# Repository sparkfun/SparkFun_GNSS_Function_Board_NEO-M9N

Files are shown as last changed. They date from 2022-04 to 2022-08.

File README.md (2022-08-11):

SparkFun MicroMod GNSS Function Board - NEO-M9N
========================================

SparkFun MicroMod GNSS Function Board - NEO-M9N (https://www.sparkfun.com/products/18378)

[*SparkFun MicroMod GNSS Function Board - NEO-M9N (GPS-18378)*](https://www.sparkfun.com/products/18378)

The SparkFun NEO-M9N GNSS Function Board is a high quality, geospatial board with equally impressive configuration options. The NEO-M9N module that is populated on this board is a 92-channel u-blox M9 engine GNSS receiver, meaning it can receive signals from the GPS, GLONASS, Galileo, and BeiDou constellations with ~1.5 meter accuracy. This Function Board supports concurrent reception of four GNSS. This maximizes position accuracy in challenging conditions, increasing precision and decreases lock time; and thanks to the on-board rechargeable battery, you'll have backup power enabling the GPS to get a hot lock within seconds!

Utilizing our handy M.2 MicroMod connector, no soldering is required to connect it to your system. Simply match up the key on your processor and function board's beveled edge connector to their respective key on the M.2 connector, then secure them to the Main Board with screws. Once connected, you'll have the option of choosing either the UART, SPI, or I<sup>2</sup>C (u-blox calls this Display Data Channel) port to communicate with the NEO-M9N.

The NEO-M9N module detects jamming and spoofing events and can reports them to the host, so that the system can react to such events. A SAW (Surface Acoustic Wave) filter combined with an LNA (Low Noise Amplifier) in the RF path is integrated into the NEO-M9N module which allows normal operation even under strong RF interferences.

U-blox based GPS products are configurable using the popular, but dense, Windows program called u-center. Plenty of different functions can be configured on the NEO-M9N: baud rates, update rates, geofencing, spoofing detection, external interrupts, SBAS/D-GPS, etc. All of this can be done within the [SparkFun Arduino Library](https://github.com/sparkfun/SparkFun_u-blox_GNSS_Arduino_Library) via the I<sup>2</sup>C bus!

The SparkFun GNSS Function Board - NEO-M9N includes a USB type C connector when configuring the module with u-center. Power is provided through the Function Board's edge pins and regulated down through the 3.3V voltage regulator. Two status LEDs are also included for 3V3 and PPS, which can be disabled by cutting the jumpers on the back of the board. A 1x3 header is populated on the board and includes a 2-pin selectable jumper when selecting the communication protocol between SPI or Serial/I<sup>2</sup>C. For advanced users, there are jumpers to disable the write protection for the EEPROM (WP), disconnecting the pull-up resistors (I2C), and placing the module in safe boot mode (SAFEBOOT). A U.FL connector is provided to connect a GNSS antenna of your choice to the module.  The board is equipped with an on-board rechargeable battery that provides power to the RTC on the NEO-M9N.  This reduces the time-to-first fix from a cold start (~24s) to a hot start (~2s). The battery will maintain RTC and GNSS orbit data without being connected to power for plenty of time. 

Repository Contents
-------------------

* **/Hardware** - Eagle design files (.brd, .sch)
* **/Production** - Production panel files (.brd)

Documentation
--------------

* **[Installing an Arduino Library Guide](https://learn.sparkfun.com/tutorials/installing-an-arduino-library/all)** - Basic information on how to install an Arduino library.
* **[Library](https://github.com/sparkfun/SparkFun_u-blox_GNSS_Arduino_Library)** - Arduino Library the SparkFun MicroMod GNSS Function Board - NEO-M9N.
* **[Hookup Guide](https://learn.sparkfun.com/tutorials/1999)** - Basic hookup guide for the SparkFun MicroMod GNSS Function Board - NEO-M9N.

Product Versions
----------------

* [GPS-18378](https://www.sparkfun.com/products/18378) - Initial release

Version History
---------------

* v1.2 - Initial Release

License Information
-------------------

This product is _**open source**_! 

Please review the LICENSE.md file for license information. 

If you have any questions or concerns on licensing, please contact technical support on our [SparkFun forums](https://forum.sparkfun.com/viewforum.php?f=152).

Distributed as-is; no warranty is given.

- Your friends at SparkFun.

_<COLLABORATION CREDIT>_

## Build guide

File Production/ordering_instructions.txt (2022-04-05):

panel size, 128x137mm
PCB thickness, 0.8mm
number of layers, 2
bevel, Gold Fingers + 45° Finger Chamfered
soldermask color, Red
silkscreen color, White
oz copper, 1oz
finish, ENIG
stencils, top
pcs per panel, 6
min trace width, 0.2032mm / 0.0080in
min drill size, 0.3048mm / 0.0120in

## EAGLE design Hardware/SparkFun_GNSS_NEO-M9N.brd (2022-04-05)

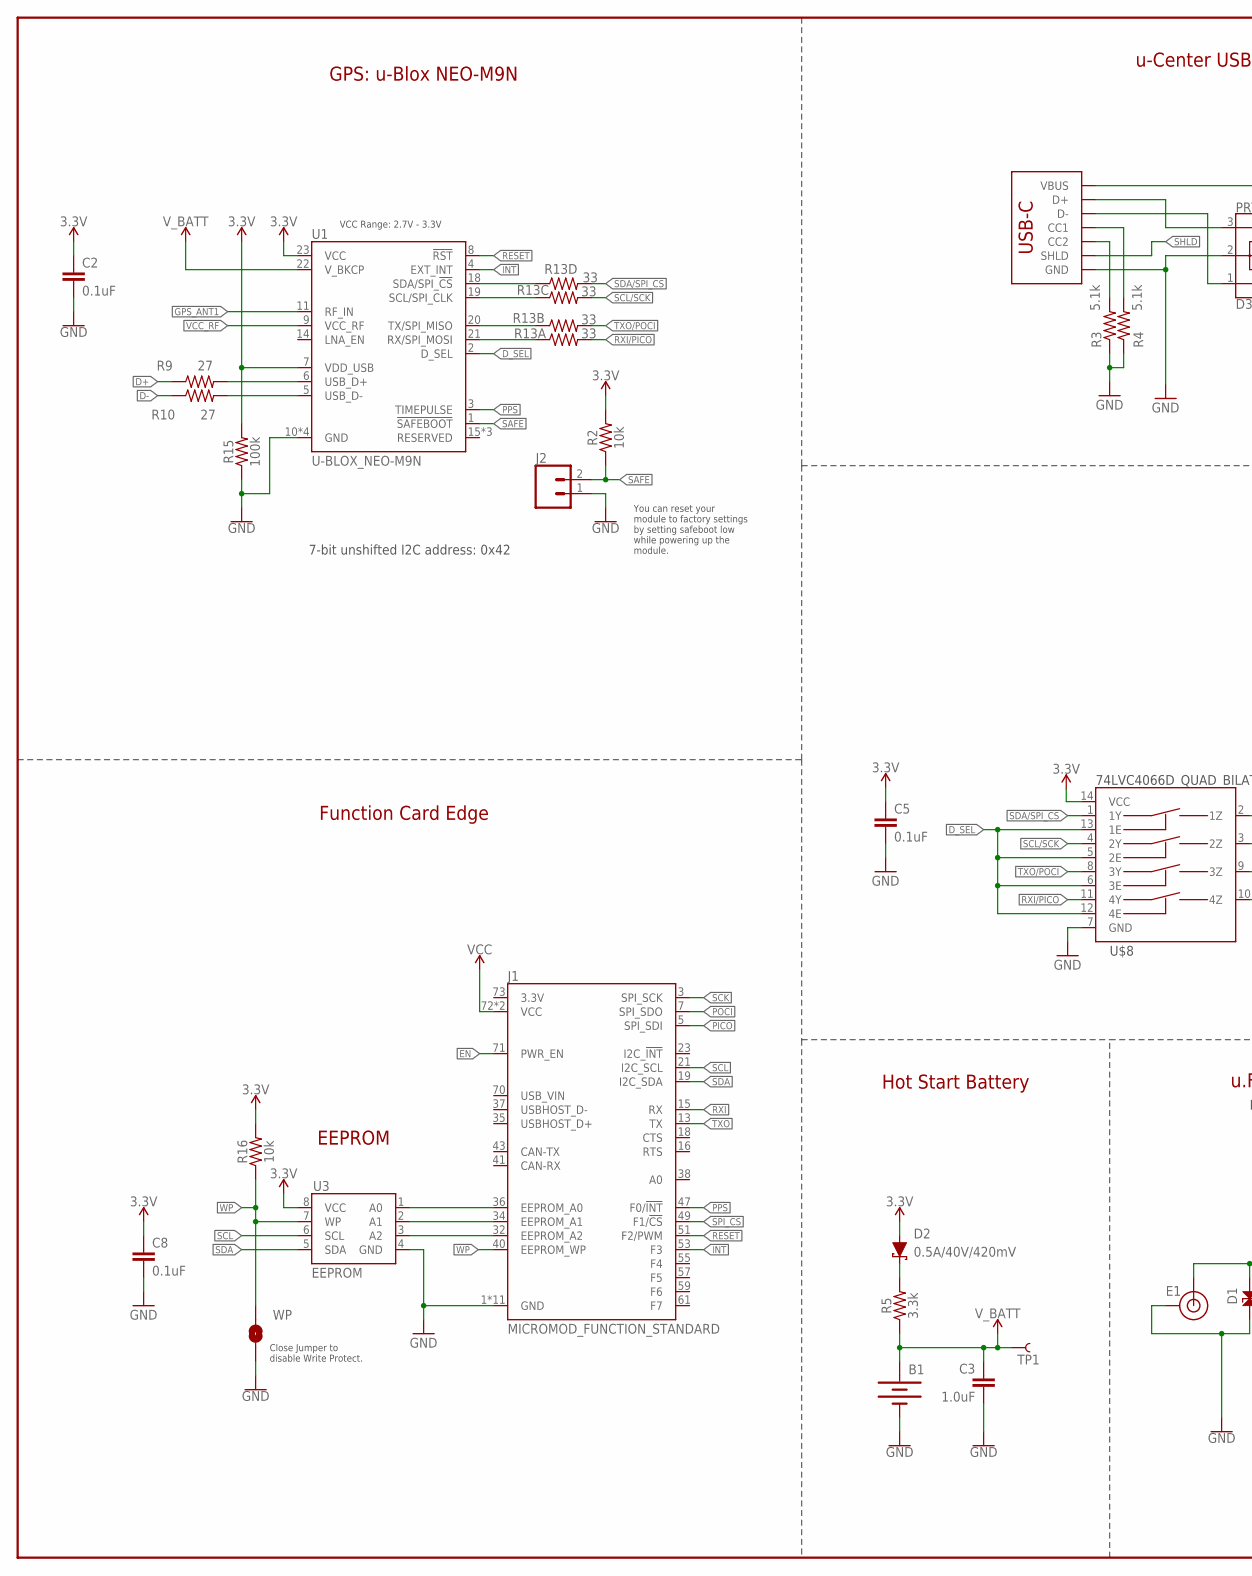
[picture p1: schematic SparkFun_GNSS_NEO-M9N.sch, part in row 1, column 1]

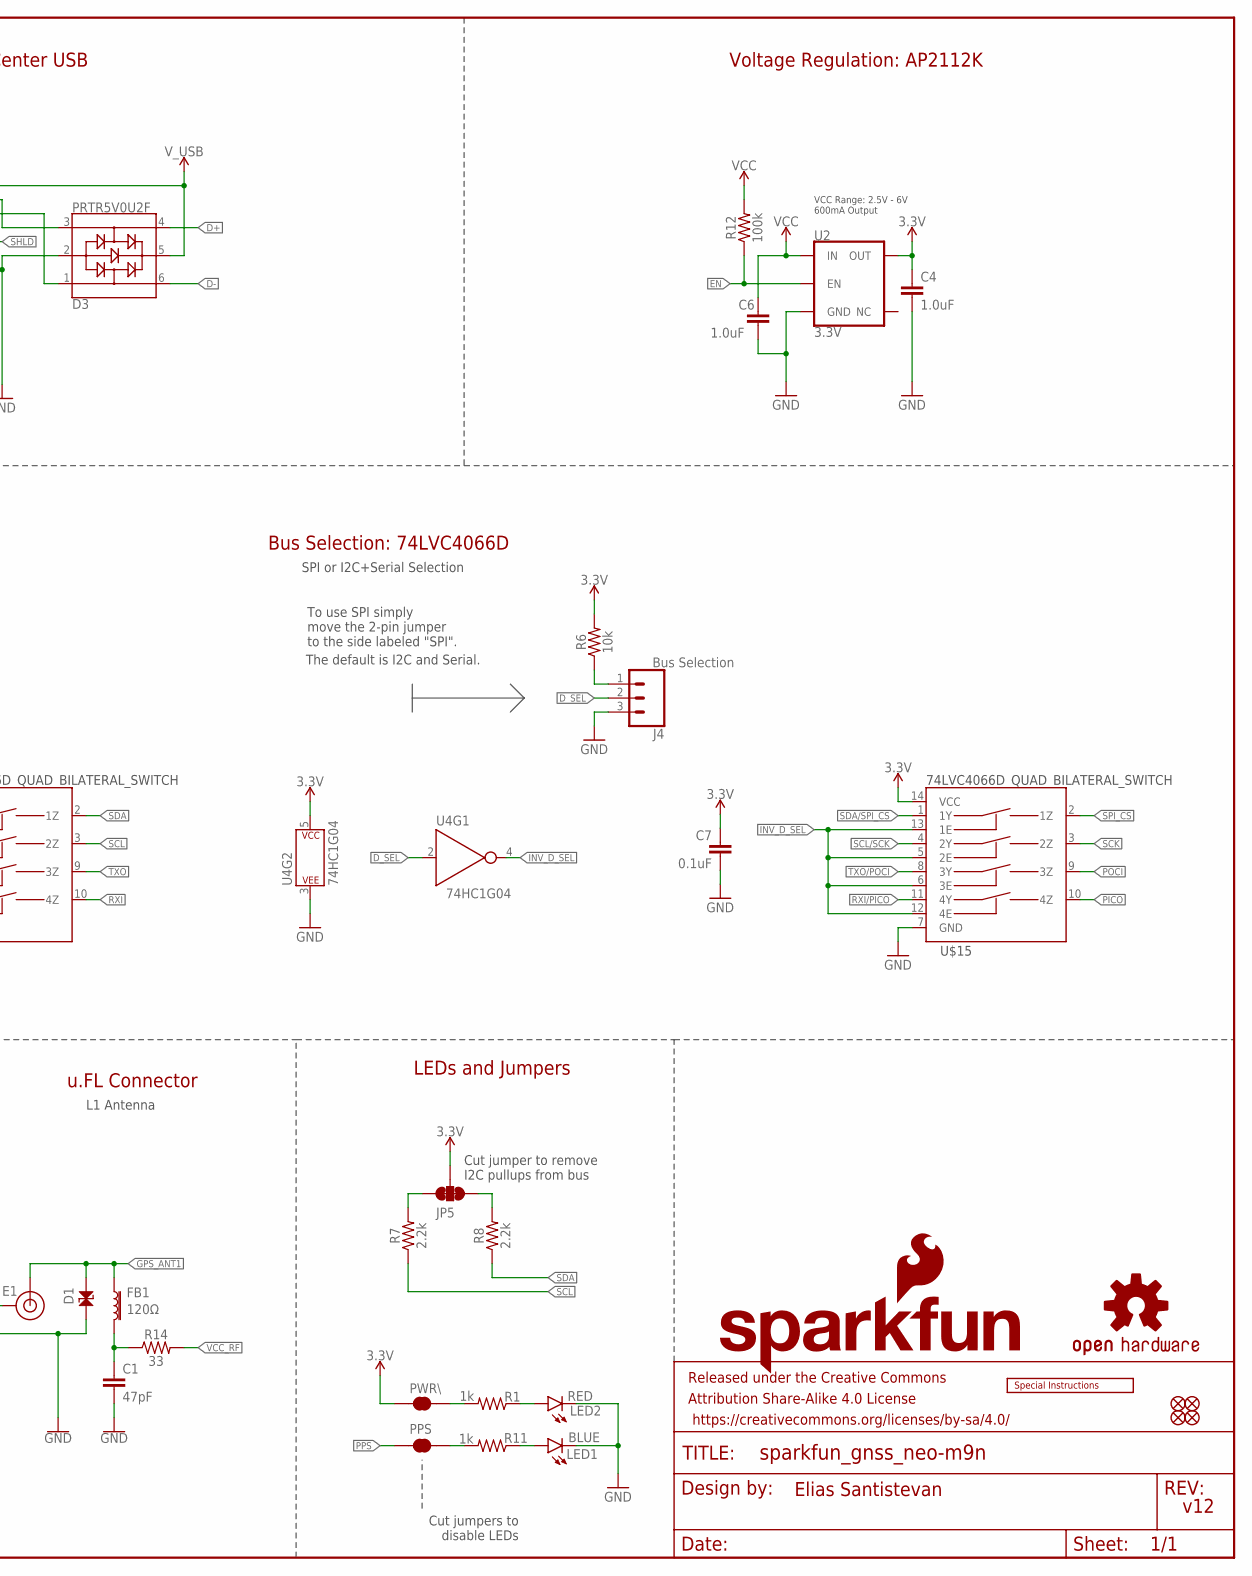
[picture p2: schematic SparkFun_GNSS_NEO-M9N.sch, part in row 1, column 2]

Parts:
B1: 6.8MM_COIN_CELL; MS421R_IV03E
C1: 47pF; 0402
C2: 0.1uF; 0402-TIGHT
C3, C4, C6: 1.0uF; 0603
C5, C7, C8: 0.1uF; 0603
D1: PESD0402-0402T; 0402-TIGHT
D2: 0.5A/40V/420mV; SOD-323
D3: PRTR5V0U2F; SOT886
E1: U.FL
FB1: 120Ω; 0402
FD1, FD2, FD3, FD4: FIDUCIAL1X2; FIDUCIAL-1X2
FRAME2: FRAME-LEDGER; CREATIVE_COMMONS
J1: MICROMOD_FUNCTION_STANDARD; M.2-CARD-E-22_FUNCTION_STANDARD
J2: CONN_02; 1X02
J3: USB_C_2-LAYER_PADS; USB-C-16P-2LAYER-PADS
J4: Bus Selection; 1X03_LOCK
JP5: JUMPER-SMT_3_2-NC_TRACE_SILK; SMT-JUMPER_3_2-NC_TRACE_SILK
LED1: BLUE; LED-0603
LED2: RED; LED-0603
LOGO1: SPECIAL_INSTRUCTIONS-ORDERING; ORDERING_INSTRUCTIONS
LOGO2: SFE_LOGO_NAME_FLAME.2_INCH; SFE_LOGO_NAME_FLAME_.2
LOGO3: OSHW-LOGOS; OSHW-LOGO-S
PPS: JUMPER-SMT_2_NC_TRACE_SILK; SMT-JUMPER_2_NC_TRACE_SILK
PWR\: JUMPER-SMT_2_NC_TRACE_SILK; SMT-JUMPER_2_NC_TRACE_SILK
R1, R11: 1k; 0603
R2, R6, R16: 10k; 0603
R3, R4: 5.1k; 0603
R5: 3.3k; 0603
R7, R8: 2.2k; 0603
R9, R10: 27; 0603
R12, R15: 100k; 0603
R13: 33; 1206_RA
R14: 33; 0402
TP1: TEST-POINT3X4; PAD.03X.04
U1: U-BLOX_NEO-M9N; NEO-M9N/M8T/M8U/D9S
U2: 3.3V; SOT23-5
U3: EEPROM; SO08
U4: 74HC1G04; SOT353
U$8, U$15: 74LVC4066D_QUAD_BILATERAL_SWITCH; SO14
WP: JUMPER-SMT_2_NO_SILK; SMT-JUMPER_2_NO_SILK

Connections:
3.3V: C2.1, C4.1, C5.1, C7.1, C8.1, D2.A, JP5.2, PWR\.2, R2.2, R6.2, R15.2, R16.2, U1.7 (VDD_USB), U1.23 (VCC), U2.5 (OUT), U3.8 (VCC), U4.5 (P$V+), U$8.14 (VCC), U$15.14 (VCC)
!RESET: J1.51 (F2/PWM), U1.8 (!RST)
!SAFE: J2.2, R2.1, U1.1 (!SAFEBOOT!)
A0: J1.36 (EEPROM_A0), U3.1 (A0)
A1: J1.34 (EEPROM_A1), U3.2 (A1)
A2: J1.32 (EEPROM_A2), U3.3 (A2)
D+: D3.4, R9.1
D-: D3.6, R10.1
D_SEL: J4.2, U1.2 (D_SEL), U4.2 (A), U$8.5 (2E), U$8.6 (3E), U$8.12 (4E), U$8.13 (1E)
EN: J1.71 (PWR_EN), R12.1, U2.3 (EN)
GND: B1.-, C1.2, C2.2, C3.2, C4.2, C5.2, C6.2, C7.2, C8.2, D1.1, D3.2, E1.1 (GND), E1.2 (GND), J1.1 (GND), J1.33 (GND), J1.39 (GND), J1.45 (GND), J1.75 (GND), J1.GND1 (GND), J1.GND2 (GND), J1.GND3 (GND), J1.GND4 (GND), J1.GND5 (GND), J1.GND6 (GND), J2.1, J3.GND, J3.GND2 (GND), J4.3, LED1.C, LED2.C, R3.1, R4.1, R15.1, U1.10 (GND), U1.12 (GND), U1.13 (GND), U1.24 (GND), U2.2 (GND), U3.4 (GND), U4.3 (P$V-), U$8.7 (GND), U$15.7 (GND), WP.1
GPS_ANT1: D1.2, E1.FEED (SIGNAL), FB1.1, U1.11 (RF_IN)
INT: J1.53 (F3), U1.4 (EXT_INT)
INV_D_SEL: U4.4 (Y), U$15.5 (2E), U$15.6 (3E), U$15.12 (4E), U$15.13 (1E)
unnamed: PWR\.1, R1.2
unnamed: LED1.A, R11.1
unnamed: C1.1, FB1.2, R14.1
unnamed: PPS.1, R11.2
unnamed: JP5.1, R8.2
unnamed: D2.C, R5.2
unnamed: J3.A5 (CC1), R4.2
unnamed: JP5.3, R7.2
unnamed: J3.B5 (CC2), R3.2
unnamed: LED2.A, R1.1
unnamed: R9.2, U1.6 (USB_D+)
unnamed: R10.2, U1.5 (USB_D-)
unnamed: J4.1, R6.1
PICO: J1.5 (SPI_SDI), U$15.10 (4Z)
POCI: J1.7 (SPI_SDO), U$15.9 (3Z)
PPS: J1.47 (F0/!INT!), PPS.2, U1.3 (TIMEPULSE)
RXI: J1.15 (RX), U$8.10 (4Z)
RXI/PICO: R13.P8 (2), U$8.11 (4Y), U$15.11 (4Y)
RXLV: R13.P1 (1), U1.21 (RX/SPI_MOSI)
SCK: J1.3 (SPI_SCK), U$15.3 (2Z)
SCL: J1.21 (I2C_SCL), R7.1, U3.6 (SCL), U$8.3 (2Z)
SCL/SCK: R13.P6 (2), U$8.4 (2Y), U$15.4 (2Y)
SCL_LV: R13.P3 (1), U1.19 (SCL/SPI_CLK)
SDA: J1.19 (I2C_SDA), R8.1, U3.5 (SDA), U$8.2 (1Z)
SDA/SPI_!CS!: R13.P5 (2), U$8.1 (1Y), U$15.1 (1Y)
SDA_LV: R13.P4 (1), U1.18 (SDA/SPI_!CS!)
SHLD: J3.SHLD1 (SHLD), J3.SHLD2 (SHLD), J3.SHLD3 (SHLD), J3.SHLD4 (SHLD)
SPI_!CS!: J1.49 (F1/!CS!), U$15.2 (1Z)
TXLV: R13.P2 (1), U1.20 (TX/SPI_MISO)
TXO: J1.13 (TX), U$8.9 (3Z)
TXO/POCI: R13.P7 (2), U$8.8 (3Y), U$15.8 (3Y)
USB_D+: D3.3, J3.A6 (D+), J3.B6 (D+)
USB_D-: D3.1, J3.A7 (D-), J3.B7 (D-)
VCC: C6.1, J1.72 (VCC), J1.74 (VCC), R12.2, U2.1 (IN)
VCC_RF: R14.2, U1.9 (VCC_RF)
V_BATT: B1.+, C3.1, R5.1, TP1.1, U1.22 (V_BKCP)
V_USB: D3.5, J3.VBUS1 (VBUS), J3.VBUS2 (VBUS)
WP: J1.40 (EEPROM_WP), R16.1, U3.7 (WP), WP.2

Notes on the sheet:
v12
7-bit unshifted I2C address: 0x42
Cut jumper to remove I2C pullups from bus
Cut jumpers to disable LEDs
Elias Santistevan
LEDs and Jumpers
Hot Start Battery
GPS: u-Blox NEO-M9N
u.FL Connector
VCC Range: 2.7V - 3.3V
VCC Range: 2.5V - 6V 600mA Output
u-Center USB
Function Card Edge
EEPROM
Voltage Regulation: AP2112K
L1 Antenna
Bus Selection: 74LVC4066D
To use SPI simply move the 2-pin jumper to the side labeled "SPI".
SPI or I2C+Serial Selection
The default is I2C and Serial.
Close Jumper to disable Write Protect.
You can reset your module to factory settings by setting safeboot low while powering up the module.

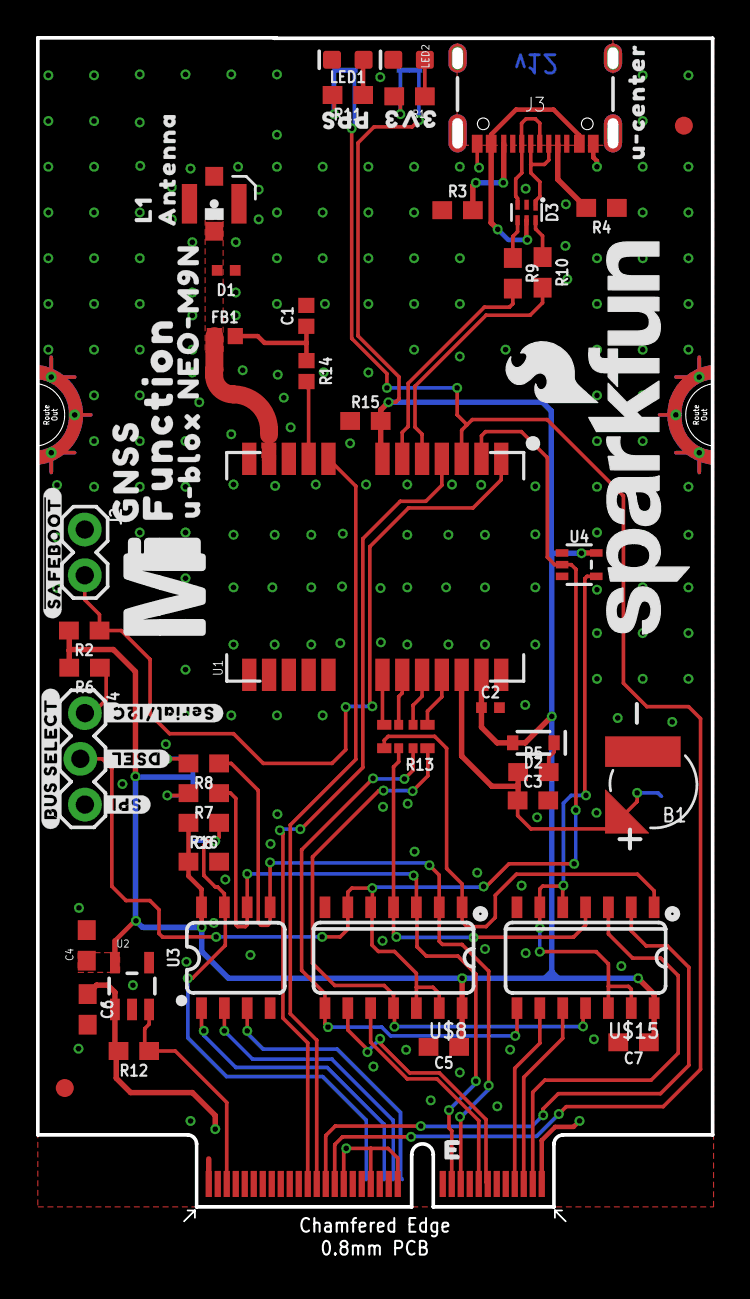
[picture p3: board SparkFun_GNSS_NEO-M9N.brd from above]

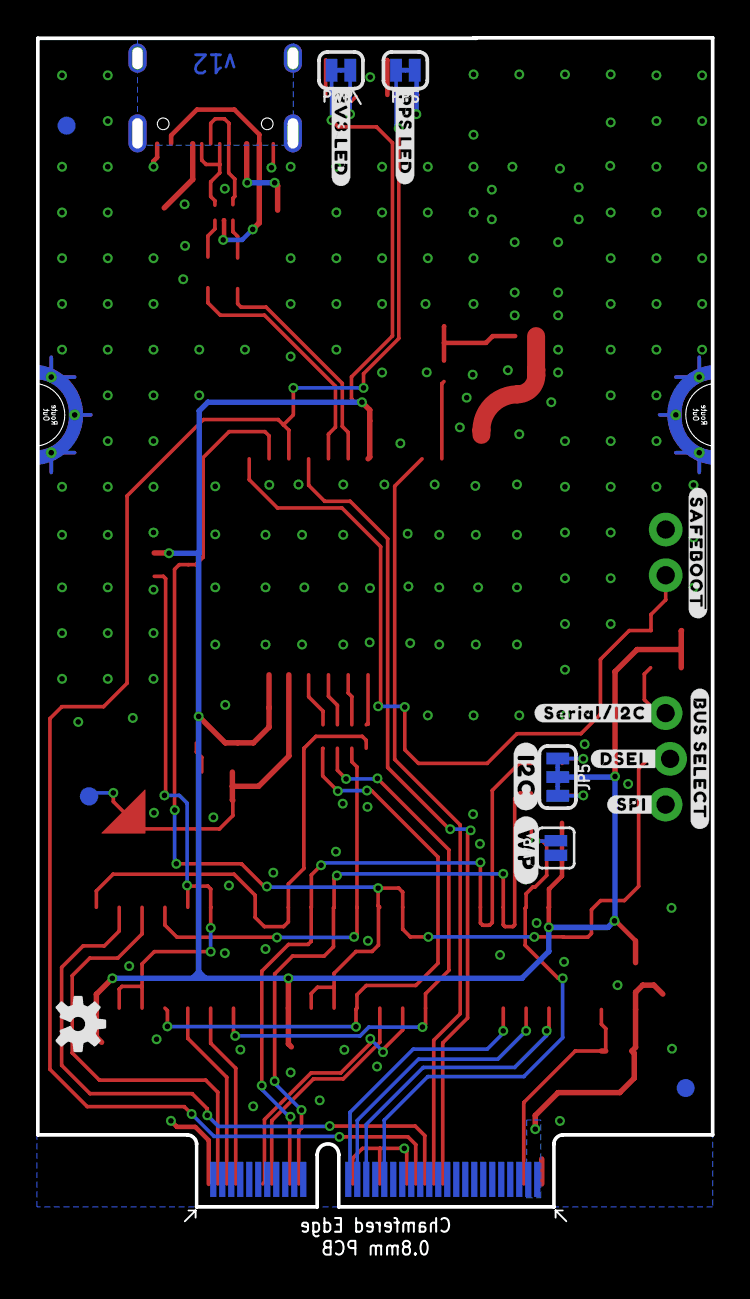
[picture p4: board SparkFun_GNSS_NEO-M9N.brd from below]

Board: 2 copper layers, 37.5 x 65.7 mm, 79 parts (17 on the bottom side), 52 nets.

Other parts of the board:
U$1: 3V313
U$2: PPS13
U$3: FUNCTION521
U$4, U$23: ##SAFEBOOT##882188213
U$5: U#BLOX11
U$6: NEO#M9N12
U$7: ANTENNA14
U$9: U#CENTER15
U$10: #I2C#18
U$11: MICROMOD_MI_LOGO_1
U$12: #3V3_LED#403132222514
U$13: #PPS_LED#403132222514
U$14: L1321542
U$16, U$24: #SPI#40313521
U$17, U$26: #SERIAL#I2C#40313523
U$18, U$22: #BUS_SELECT#509
U$19, U$25: #DSEL#40313522
U$20: #WP#13215403132222564
U$21: GNSS2222502

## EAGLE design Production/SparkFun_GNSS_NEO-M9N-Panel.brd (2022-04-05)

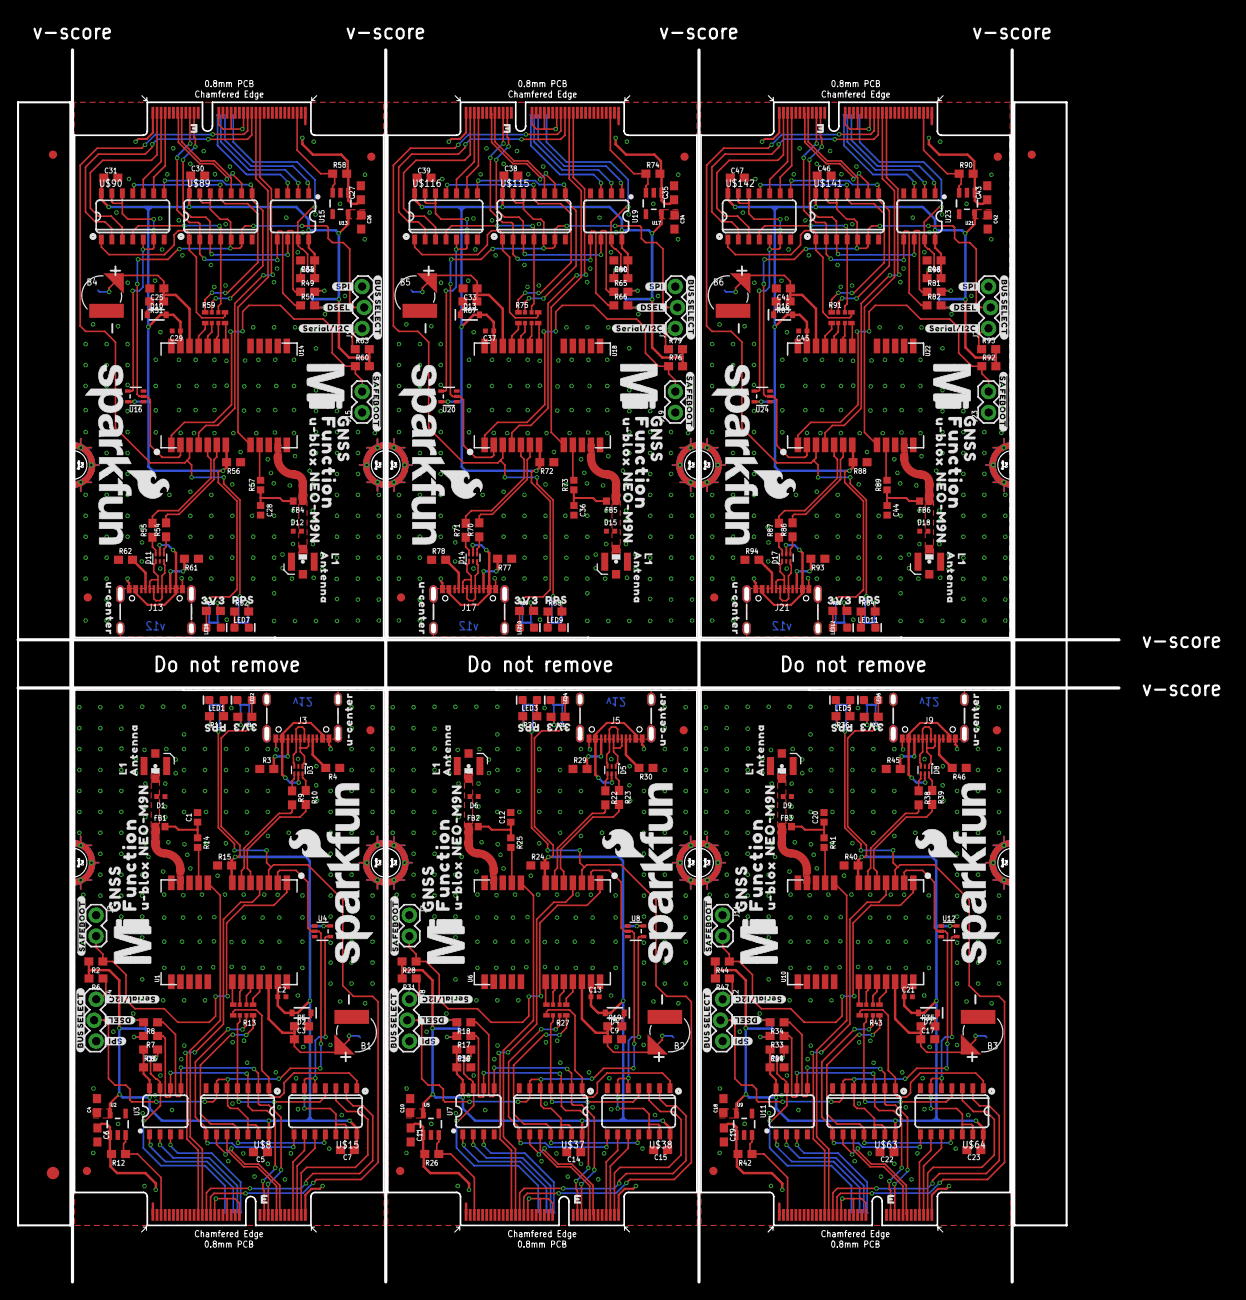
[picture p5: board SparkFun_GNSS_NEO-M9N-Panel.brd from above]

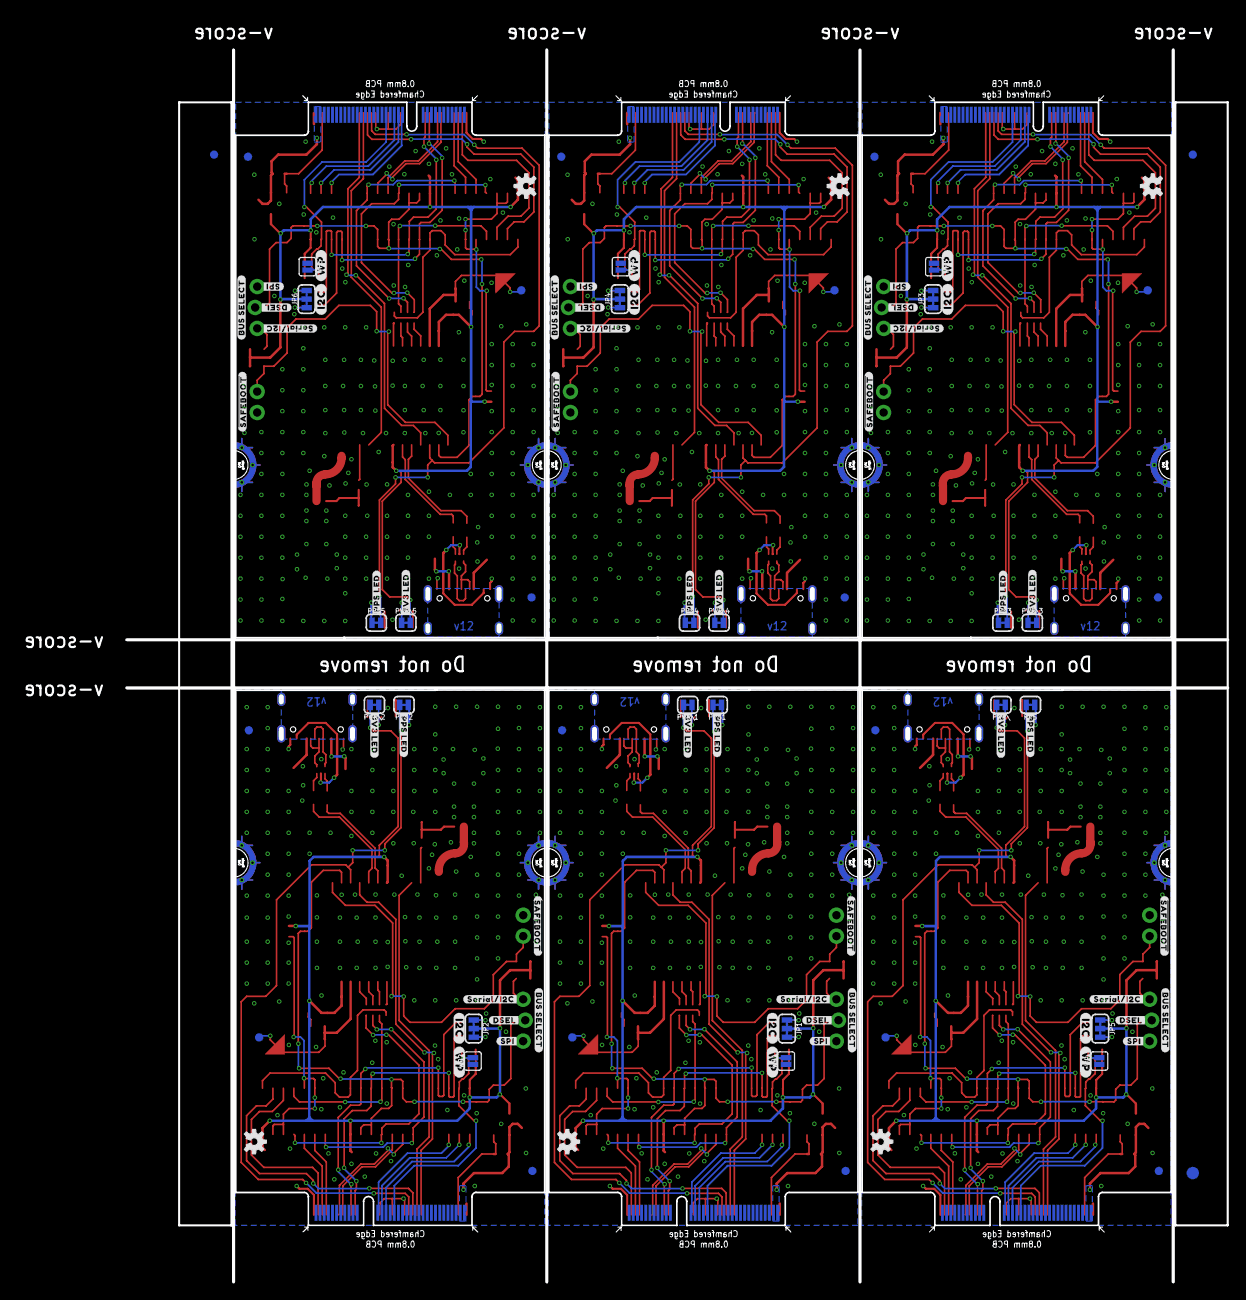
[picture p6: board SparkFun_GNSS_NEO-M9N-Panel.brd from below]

Board: 2 copper layers, 133.6 x 149.5 mm, 468 parts (105 on the bottom side), 312 nets.

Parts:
B1, B2, B3, B4, B5, B6: 6.8MM_COIN_CELL; MS421R_IV03E
C1, C12, C20, C28, C36, C44: 47pF; 0402
C2, C13, C21, C29, C37, C45: 0.1uF; 0402-TIGHT
C3, C4, C6, C9, C10, C11, C17, C18, C19, C25, C26, C27, C33, C34, C35, C41, C42, C43: 1.0uF; 0603
C5, C7, C8, C14, C15, C16, C22, C23, C24, C30, C31, C32, C38, C39, C40, C46, C47, C48: 0.1uF; 0603
D1, D6, D9, D12, D15, D18: PESD0402-0402T; 0402-TIGHT
D2, D4, D7, D10, D13, D16: 0.5A/40V/420mV; SOD-323
D3, D5, D8, D11, D14, D17: PRTR5V0U2F; SOT886
E1, E2, E3, E4, E5, E6: U.FL
E$1, E$2, E$3, E$4: FIDUCIAL-1X2
E$5, E$6: FIDUCIAL-1.5X3
FB1, FB2, FB3, FB4, FB5, FB6: 120Ω; 0402
FD1, FD2, FD3, FD4, FD5, FD6, FD7, FD8, FD9, FD10, FD11, FD12, FD13, FD14, FD15, FD16, FD17, FD18, FD19, FD20, FD21, FD22, FD23, FD24: FIDUCIAL1X2; FIDUCIAL-1X2
J1, J6, J10, J14, J18, J22: MICROMOD_FUNCTION_STANDARD; M.2-CARD-E-22_FUNCTION_STANDARD
J2, J7, J11, J15, J19, J23: 1X02
J3, J5, J9, J13, J17, J21: USB-C-16P-2LAYER-PADS
J4, J8, J12, J16, J20, J24: Bus Selection; 1X03_LOCK
JP1, JP2, JP3, JP4, JP5, JP6: JUMPER-SMT_3_2-NC_TRACE_SILK; SMT-JUMPER_3_2-NC_TRACE_SILK
LED1, LED3, LED5, LED7, LED9, LED11: BLUE; LED-0603
LED2, LED4, LED6, LED8, LED10, LED12: RED; LED-0603
LOGO1, LOGO2, LOGO5, LOGO7, LOGO9, LOGO11: SFE_LOGO_NAME_FLAME.2_INCH; SFE_LOGO_NAME_FLAME_.2
LOGO3, LOGO4, LOGO6, LOGO8, LOGO10, LOGO12: OSHW-LOGOS; OSHW-LOGO-S
PPS, PPS1, PPS2, PPS3, PPS4, PPS5: JUMPER-SMT_2_NC_TRACE_SILK; SMT-JUMPER_2_NC_TRACE_SILK
PWR\, PWR\1, PWR\2, PWR\3, PWR\4, PWR\5: JUMPER-SMT_2_NC_TRACE_SILK; SMT-JUMPER_2_NC_TRACE_SILK
R1, R11, R20, R21, R36, R37, R52, R53, R68, R69, R84, R85: 1k; 0603
R2, R6, R16, R28, R31, R32, R44, R47, R48, R60, R63, R64, R76, R79, R80, R92, R95, R96: 10k; 0603
R3, R4, R29, R30, R45, R46, R61, R62, R77, R78, R93, R94: 5.1k; 0603
R5, R19, R35, R51, R67, R83: 3.3k; 0603
R7, R8, R17, R18, R33, R34, R49, R50, R65, R66, R81, R82: 2.2k; 0603
R9, R10, R22, R23, R38, R39, R54, R55, R70, R71, R86, R87: 27; 0603
R12, R15, R24, R26, R40, R42, R56, R58, R72, R74, R88, R90: 100k; 0603
R13, R27, R43, R59, R75, R91: 33; 1206_RA
R14, R25, R41, R57, R73, R89: 33; 0402
TP1, TP2, TP3, TP4, TP5, TP6: TEST-POINT3X4; PAD.03X.04
U1, U6, U10, U14, U18, U22: U-BLOX_NEO-M9N; NEO-M9N/M8T/M8U/D9S
U2, U5, U9, U13, U17, U21: 3.3V; SOT23-5
U3, U7, U11, U15, U19, U23: EEPROM; SO08
U4, U8, U12, U16, U20, U24: 74HC1G04; SOT353
U$1, U$27, U$53, U$79, U$105, U$131: 3V313
U$2, U$28, U$54, U$80, U$106, U$132: PPS13
U$3, U$34, U$60, U$86, U$112, U$138: FUNCTION521
U$4, U$23, U$48, U$49, U$74, U$75, U$100, U$101, U$126, U$127, U$152, U$153: ##SAFEBOOT##882188213
U$5, U$29, U$55, U$81, U$107, U$133: U#BLOX11
U$6, U$30, U$56, U$82, U$108, U$134: NEO#M9N12
U$7, U$31, U$57, U$83, U$109, U$135: ANTENNA14
U$8, U$15, U$37, U$38, U$63, U$64, U$89, U$90, U$115, U$116, U$141, U$142: 74LVC4066D_QUAD_BILATERAL_SWITCH; SO14
U$9, U$32, U$58, U$84, U$110, U$136: U#CENTER15
U$10, U$33, U$59, U$85, U$111, U$137: #I2C#18
U$11, U$35, U$61, U$87, U$113, U$139: MICROMOD_MI_LOGO_1
U$12, U$45, U$71, U$97, U$123, U$149: #3V3_LED#403132222514
U$13, U$46, U$72, U$98, U$124, U$150: #PPS_LED#403132222514
U$14, U$36, U$62, U$88, U$114, U$140: L1321542
U$16, U$24, U$41, U$50, U$67, U$76, U$93, U$102, U$119, U$128, U$145, U$154: #SPI#40313521
U$17, U$26, U$42, U$52, U$68, U$78, U$94, U$104, U$120, U$130, U$146, U$156: #SERIAL#I2C#40313523
U$18, U$22, U$39, U$47, U$65, U$73, U$91, U$99, U$117, U$125, U$143, U$151: #BUS_SELECT#509
U$19, U$25, U$40, U$51, U$66, U$77, U$92, U$103, U$118, U$129, U$144, U$155: #DSEL#40313522
U$20, U$43, U$69, U$95, U$121, U$147: #WP#13215403132222564
U$21, U$44, U$70, U$96, U$122, U$148: GNSS2222502
WP, WP1, WP2, WP3, WP4, WP5: JUMPER-SMT_2_NO_SILK; SMT-JUMPER_2_NO_SILK

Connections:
3.3V: C2.1, C4.1, C5.1, C7.1, C8.1, D2.A, JP5.2, PWR\.2, R2.2, R6.2, R15.2, R16.2, U1.7, U1.23, U2.5, U3.8, U4.5, U$8.14, U$15.14
3.3V1: C10.1, C13.1, C14.1, C15.1, C16.1, D4.A, JP1.2, PWR\1.2, R24.2, R28.2, R31.2, R32.2, U5.5, U6.7, U6.23, U7.8, U8.5, U$37.14, U$38.14
3.3V2: C18.1, C21.1, C22.1, C23.1, C24.1, D7.A, JP2.2, PWR\2.2, R40.2, R44.2, R47.2, R48.2, U9.5, U10.7, U10.23, U11.8, U12.5, U$63.14, U$64.14
3.3V3: C26.1, C29.1, C30.1, C31.1, C32.1, D10.A, JP3.2, PWR\3.2, R56.2, R60.2, R63.2, R64.2, U13.5, U14.7, U14.23, U15.8, U16.5, U$89.14, U$90.14
3.3V4: C34.1, C37.1, C38.1, C39.1, C40.1, D13.A, JP4.2, PWR\4.2, R72.2, R76.2, R79.2, R80.2, U17.5, U18.7, U18.23, U19.8, U20.5, U$115.14, U$116.14
3.3V5: C42.1, C45.1, C46.1, C47.1, C48.1, D16.A, JP6.2, PWR\5.2, R88.2, R92.2, R95.2, R96.2, U21.5, U22.7, U22.23, U23.8, U24.5, U$141.14, U$142.14
!RESET: J1.51, U1.8
!RESET1: J6.51, U6.8
!RESET2: J10.51, U10.8
!RESET3: J14.51, U14.8
!RESET4: J18.51, U18.8
!RESET5: J22.51, U22.8
!SAFE: J2.2, R2.1, U1.1
!SAFE1: J7.2, R28.1, U6.1
!SAFE2: J11.2, R44.1, U10.1
!SAFE3: J15.2, R60.1, U14.1
!SAFE4: J19.2, R76.1, U18.1
!SAFE5: J23.2, R92.1, U22.1
A0: J1.36, U3.1
A1: J1.34, U3.2
A2: J1.32, U3.3
A3: J6.36, U7.1
A4: J6.32, U7.3
A5: J6.34, U7.2
A6: J10.36, U11.1
A7: J10.32, U11.3
A8: J10.34, U11.2
A9: J14.36, U15.1
A10: J14.32, U15.3
A11: J14.34, U15.2
A12: J18.36, U19.1
A13: J18.32, U19.3
A14: J18.34, U19.2
A15: J22.36, U23.1
A16: J22.32, U23.3
A17: J22.34, U23.2
D+: D3.4, R9.1
D+1: D5.4, R22.1
D+2: D8.4, R38.1
D+3: D11.4, R54.1
D+4: D14.4, R70.1
D+5: D17.4, R86.1
D-: D3.6, R10.1
D-1: D5.6, R23.1
D-2: D8.6, R39.1
D-3: D11.6, R55.1
D-4: D14.6, R71.1
D-5: D17.6, R87.1
D_SEL: J4.2, U1.2, U4.2, U$8.5, U$8.6, U$8.12, U$8.13
D_SEL1: J8.2, U6.2, U8.2, U$37.5, U$37.6, U$37.12, U$37.13
D_SEL2: J12.2, U10.2, U12.2, U$63.5, U$63.6, U$63.12, U$63.13
D_SEL3: J16.2, U14.2, U16.2, U$89.5, U$89.6, U$89.12, U$89.13
D_SEL4: J20.2, U18.2, U20.2, U$115.5, U$115.6, U$115.12, U$115.13
D_SEL5: J24.2, U22.2, U24.2, U$141.5, U$141.6, U$141.12, U$141.13
EN: J1.71, R12.1, U2.3
EN1: J6.71, R26.1, U5.3
EN2: J10.71, R42.1, U9.3
EN3: J14.71, R58.1, U13.3
EN4: J18.71, R74.1, U17.3
EN5: J22.71, R90.1, U21.3
GND: B1.-, C1.2, C2.2, C3.2, C4.2, C5.2, C6.2, C7.2, C8.2, D1.1, D3.2, E1.1, E1.2, J1.1, J1.33, J1.39, J1.45, J1.75, J1.GND1, J1.GND2, J1.GND3, J1.GND4, J1.GND5, J1.GND6, J2.1, J3.GND, J3.GND2, J4.3, LED1.C, LED2.C, R3.1, R4.1, R15.1, U1.10, U1.12, U1.13, U1.24, U2.2, U3.4, U4.3, U$8.7, U$15.7, WP.1
GND1: B2.-, C9.2, C10.2, C11.2, C12.2, C13.2, C14.2, C15.2, C16.2, D5.2, D6.1, E2.1, E2.2, J5.GND, J5.GND2, J6.1, J6.33, J6.39, J6.45, J6.75, J6.GND1, J6.GND2, J6.GND3, J6.GND4, J6.GND5, J6.GND6, J7.1, J8.3, LED3.C, LED4.C, R24.1, R29.1, R30.1, U5.2, U6.10, U6.12, U6.13, U6.24, U7.4, U8.3, U$37.7, U$38.7, WP1.1
GND2: B3.-, C17.2, C18.2, C19.2, C20.2, C21.2, C22.2, C23.2, C24.2, D8.2, D9.1, E3.1, E3.2, J9.GND, J9.GND2, J10.1, J10.33, J10.39, J10.45, J10.75, J10.GND1, J10.GND2, J10.GND3, J10.GND4, J10.GND5, J10.GND6, J11.1, J12.3, LED5.C, LED6.C, R40.1, R45.1, R46.1, U9.2, U10.10, U10.12, U10.13, U10.24, U11.4, U12.3, U$63.7, U$64.7, WP2.1
GND3: B4.-, C25.2, C26.2, C27.2, C28.2, C29.2, C30.2, C31.2, C32.2, D11.2, D12.1, E4.1, E4.2, J13.GND, J13.GND2, J14.1, J14.33, J14.39, J14.45, J14.75, J14.GND1, J14.GND2, J14.GND3, J14.GND4, J14.GND5, J14.GND6, J15.1, J16.3, LED7.C, LED8.C, R56.1, R61.1, R62.1, U13.2, U14.10, U14.12, U14.13, U14.24, U15.4, U16.3, U$89.7, U$90.7, WP3.1
GND4: B5.-, C33.2, C34.2, C35.2, C36.2, C37.2, C38.2, C39.2, C40.2, D14.2, D15.1, E5.1, E5.2, J17.GND, J17.GND2, J18.1, J18.33, J18.39, J18.45, J18.75, J18.GND1, J18.GND2, J18.GND3, J18.GND4, J18.GND5, J18.GND6, J19.1, J20.3, LED9.C, LED10.C, R72.1, R77.1, R78.1, U17.2, U18.10, U18.12, U18.13, U18.24, U19.4, U20.3, U$115.7, U$116.7, WP4.1
GND5: B6.-, C41.2, C42.2, C43.2, C44.2, C45.2, C46.2, C47.2, C48.2, D17.2, D18.1, E6.1, E6.2, J21.GND, J21.GND2, J22.1, J22.33, J22.39, J22.45, J22.75, J22.GND1, J22.GND2, J22.GND3, J22.GND4, J22.GND5, J22.GND6, J23.1, J24.3, LED11.C, LED12.C, R88.1, R93.1, R94.1, U21.2, U22.10, U22.12, U22.13, U22.24, U23.4, U24.3, U$141.7, U$142.7, WP5.1
GPS_ANT1: D1.2, E1.FEED, FB1.1, U1.11
GPS_ANT2: D6.2, E2.FEED, FB2.1, U6.11
GPS_ANT3: D9.2, E3.FEED, FB3.1, U10.11
GPS_ANT4: D12.2, E4.FEED, FB4.1, U14.11
GPS_ANT5: D15.2, E5.FEED, FB5.1, U18.11
GPS_ANT6: D18.2, E6.FEED, FB6.1, U22.11
INT: J1.53, U1.4
INT1: J6.53, U6.4
INT2: J10.53, U10.4
INT3: J14.53, U14.4
INT4: J18.53, U18.4
INT5: J22.53, U22.4
INV_D_SEL: U4.4, U$15.5, U$15.6, U$15.12, U$15.13
INV_D_SEL1: U8.4, U$38.5, U$38.6, U$38.12, U$38.13
INV_D_SEL2: U12.4, U$64.5, U$64.6, U$64.12, U$64.13
INV_D_SEL3: U16.4, U$90.5, U$90.6, U$90.12, U$90.13
INV_D_SEL4: U20.4, U$116.5, U$116.6, U$116.12, U$116.13
INV_D_SEL5: U24.4, U$142.5, U$142.6, U$142.12, U$142.13
unnamed: PWR\.1, R1.2
unnamed: LED1.A, R11.1
unnamed: C1.1, FB1.2, R14.1
unnamed: PPS.1, R11.2
unnamed: JP5.1, R8.2
unnamed: D2.C, R5.2
unnamed: J3.A5, R4.2
unnamed: JP5.3, R7.2
unnamed: J3.B5, R3.2
unnamed: LED2.A, R1.1
unnamed: R9.2, U1.6
unnamed: R10.2, U1.5
unnamed: J4.1, R6.1
unnamed: JP1.1, R18.2
unnamed: JP1.3, R17.2
unnamed: LED3.A, R20.1
unnamed: PPS1.1, R20.2
unnamed: D4.C, R19.2
unnamed: LED4.A, R21.1
unnamed: R22.2, U6.6
unnamed: R23.2, U6.5
unnamed: PWR\1.1, R21.2
unnamed: C12.1, FB2.2, R25.1
unnamed: J5.A5, R30.2
unnamed: J5.B5, R29.2
unnamed: J8.1, R31.1
unnamed: JP2.1, R34.2
unnamed: JP2.3, R33.2
unnamed: LED5.A, R36.1
unnamed: PPS2.1, R36.2
unnamed: D7.C, R35.2
unnamed: LED6.A, R37.1
unnamed: R38.2, U10.6
unnamed: R39.2, U10.5
unnamed: PWR\2.1, R37.2
unnamed: C20.1, FB3.2, R41.1
unnamed: J9.A5, R46.2
unnamed: J9.B5, R45.2
unnamed: J12.1, R47.1
unnamed: JP3.1, R50.2
unnamed: JP3.3, R49.2
unnamed: LED7.A, R52.1
unnamed: PPS3.1, R52.2
unnamed: D10.C, R51.2
unnamed: LED8.A, R53.1
unnamed: R54.2, U14.6
unnamed: R55.2, U14.5
unnamed: PWR\3.1, R53.2
unnamed: C28.1, FB4.2, R57.1
unnamed: J13.A5, R62.2
unnamed: J13.B5, R61.2
unnamed: J16.1, R63.1
unnamed: JP4.1, R66.2
unnamed: JP4.3, R65.2
unnamed: LED9.A, R68.1
unnamed: PPS4.1, R68.2
unnamed: D13.C, R67.2
unnamed: LED10.A, R69.1
unnamed: R70.2, U18.6
unnamed: R71.2, U18.5
unnamed: PWR\4.1, R69.2
unnamed: C36.1, FB5.2, R73.1
unnamed: J17.A5, R78.2
unnamed: J17.B5, R77.2
unnamed: J20.1, R79.1
unnamed: JP6.1, R82.2
unnamed: JP6.3, R81.2
unnamed: LED11.A, R84.1
unnamed: PPS5.1, R84.2
unnamed: D16.C, R83.2
unnamed: LED12.A, R85.1
unnamed: R86.2, U22.6
unnamed: R87.2, U22.5
unnamed: PWR\5.1, R85.2
unnamed: C44.1, FB6.2, R89.1
unnamed: J21.A5, R94.2
unnamed: J21.B5, R93.2
unnamed: J24.1, R95.1
PICO: J1.5, U$15.10
PICO1: J6.5, U$38.10
PICO2: J10.5, U$64.10
PICO3: J14.5, U$90.10
PICO4: J18.5, U$116.10
PICO5: J22.5, U$142.10
POCI: J1.7, U$15.9
POCI1: J6.7, U$38.9
POCI2: J10.7, U$64.9
POCI3: J14.7, U$90.9
POCI4: J18.7, U$116.9
POCI5: J22.7, U$142.9
PPS: J1.47, PPS.2, U1.3
PPS1: J6.47, PPS1.2, U6.3
PPS2: J10.47, PPS2.2, U10.3
PPS3: J14.47, PPS3.2, U14.3
PPS4: J18.47, PPS4.2, U18.3
PPS5: J22.47, PPS5.2, U22.3
RXI: J1.15, U$8.10
RXI1: J6.15, U$37.10
RXI2: J10.15, U$63.10
RXI3: J14.15, U$89.10
RXI4: J18.15, U$115.10
RXI5: J22.15, U$141.10
RXI/PICO: R13.P8, U$8.11, U$15.11
RXI/PICO1: R27.P8, U$37.11, U$38.11
RXI/PICO2: R43.P8, U$63.11, U$64.11
RXI/PICO3: R59.P8, U$89.11, U$90.11
RXI/PICO4: R75.P8, U$115.11, U$116.11
RXI/PICO5: R91.P8, U$141.11, U$142.11
RXLV: R13.P1, U1.21
RXLV1: R27.P1, U6.21
RXLV2: R43.P1, U10.21
RXLV3: R59.P1, U14.21
RXLV4: R75.P1, U18.21
RXLV5: R91.P1, U22.21
SCK: J1.3, U$15.3
SCK1: J6.3, U$38.3
SCK2: J10.3, U$64.3
SCK3: J14.3, U$90.3
SCK4: J18.3, U$116.3
SCK5: J22.3, U$142.3
SCL: J1.21, R7.1, U3.6, U$8.3
SCL1: J6.21, R17.1, U7.6, U$37.3
SCL2: J10.21, R33.1, U11.6, U$63.3
SCL3: J14.21, R49.1, U15.6, U$89.3
SCL4: J18.21, R65.1, U19.6, U$115.3
SCL5: J22.21, R81.1, U23.6, U$141.3
SCL/SCK: R13.P6, U$8.4, U$15.4
SCL/SCK1: R27.P6, U$37.4, U$38.4
SCL/SCK2: R43.P6, U$63.4, U$64.4
SCL/SCK3: R59.P6, U$89.4, U$90.4
SCL/SCK4: R75.P6, U$115.4, U$116.4
SCL/SCK5: R91.P6, U$141.4, U$142.4
SCL_LV: R13.P3, U1.19
SCL_LV1: R27.P3, U6.19
SCL_LV2: R43.P3, U10.19
SCL_LV3: R59.P3, U14.19
SCL_LV4: R75.P3, U18.19
SCL_LV5: R91.P3, U22.19
SDA: J1.19, R8.1, U3.5, U$8.2
SDA1: J6.19, R18.1, U7.5, U$37.2
SDA2: J10.19, R34.1, U11.5, U$63.2
SDA3: J14.19, R50.1, U15.5, U$89.2
SDA4: J18.19, R66.1, U19.5, U$115.2
SDA5: J22.19, R82.1, U23.5, U$141.2
SDA/SPI_!CS!: R13.P5, U$8.1, U$15.1
SDA/SPI_!CS!1: R27.P5, U$37.1, U$38.1
SDA/SPI_!CS!2: R43.P5, U$63.1, U$64.1
SDA/SPI_!CS!3: R59.P5, U$89.1, U$90.1
SDA/SPI_!CS!4: R75.P5, U$115.1, U$116.1
SDA/SPI_!CS!5: R91.P5, U$141.1, U$142.1
SDA_LV: R13.P4, U1.18
SDA_LV1: R27.P4, U6.18
SDA_LV2: R43.P4, U10.18
SDA_LV3: R59.P4, U14.18
SDA_LV4: R75.P4, U18.18
SDA_LV5: R91.P4, U22.18
SHLD: J3.SHLD1, J3.SHLD2, J3.SHLD3, J3.SHLD4
SHLD1: J5.SHLD1, J5.SHLD2, J5.SHLD3, J5.SHLD4
SHLD2: J9.SHLD1, J9.SHLD2, J9.SHLD3, J9.SHLD4
SHLD3: J13.SHLD1, J13.SHLD2, J13.SHLD3, J13.SHLD4
SHLD4: J17.SHLD1, J17.SHLD2, J17.SHLD3, J17.SHLD4
SHLD5: J21.SHLD1, J21.SHLD2, J21.SHLD3, J21.SHLD4
SPI_!CS!: J1.49, U$15.2
SPI_!CS!1: J6.49, U$38.2
SPI_!CS!2: J10.49, U$64.2
SPI_!CS!3: J14.49, U$90.2
SPI_!CS!4: J18.49, U$116.2
SPI_!CS!5: J22.49, U$142.2
TXLV: R13.P2, U1.20
TXLV1: R27.P2, U6.20
TXLV2: R43.P2, U10.20
TXLV3: R59.P2, U14.20
TXLV4: R75.P2, U18.20
TXLV5: R91.P2, U22.20
TXO: J1.13, U$8.9
TXO1: J6.13, U$37.9
TXO2: J10.13, U$63.9
TXO3: J14.13, U$89.9
TXO4: J18.13, U$115.9
TXO5: J22.13, U$141.9
TXO/POCI: R13.P7, U$8.8, U$15.8
TXO/POCI1: R27.P7, U$37.8, U$38.8
TXO/POCI2: R43.P7, U$63.8, U$64.8
TXO/POCI3: R59.P7, U$89.8, U$90.8
TXO/POCI4: R75.P7, U$115.8, U$116.8
TXO/POCI5: R91.P7, U$141.8, U$142.8
USB_D+: D3.3, J3.A6, J3.B6
USB_D+1: D5.3, J5.A6, J5.B6
USB_D+2: D8.3, J9.A6, J9.B6
USB_D+3: D11.3, J13.A6, J13.B6
USB_D+4: D14.3, J17.A6, J17.B6
USB_D+5: D17.3, J21.A6, J21.B6
USB_D-: D3.1, J3.A7, J3.B7
USB_D-1: D5.1, J5.A7, J5.B7
USB_D-2: D8.1, J9.A7, J9.B7
USB_D-3: D11.1, J13.A7, J13.B7
USB_D-4: D14.1, J17.A7, J17.B7
USB_D-5: D17.1, J21.A7, J21.B7
VCC: C6.1, J1.72, J1.74, R12.2, U2.1
VCC1: C11.1, J6.72, J6.74, R26.2, U5.1
VCC2: C19.1, J10.72, J10.74, R42.2, U9.1
VCC3: C27.1, J14.72, J14.74, R58.2, U13.1
VCC4: C35.1, J18.72, J18.74, R74.2, U17.1
VCC5: C43.1, J22.72, J22.74, R90.2, U21.1
VCC_RF: R14.2, U1.9
VCC_RF1: R25.2, U6.9
VCC_RF2: R41.2, U10.9
VCC_RF3: R57.2, U14.9
VCC_RF4: R73.2, U18.9
VCC_RF5: R89.2, U22.9
V_BATT: B1.+, C3.1, R5.1, TP1.1, U1.22
V_BATT1: B2.+, C9.1, R19.1, TP2.1, U6.22
V_BATT2: B3.+, C17.1, R35.1, TP3.1, U10.22
V_BATT3: B4.+, C25.1, R51.1, TP4.1, U14.22
V_BATT4: B5.+, C33.1, R67.1, TP5.1, U18.22
V_BATT5: B6.+, C41.1, R83.1, TP6.1, U22.22
V_USB: D3.5, J3.VBUS1, J3.VBUS2
V_USB1: D5.5, J5.VBUS1, J5.VBUS2
V_USB2: D8.5, J9.VBUS1, J9.VBUS2
V_USB3: D11.5, J13.VBUS1, J13.VBUS2
V_USB4: D14.5, J17.VBUS1, J17.VBUS2
V_USB5: D17.5, J21.VBUS1, J21.VBUS2
WP: J1.40, R16.1, U3.7, WP.2
WP1: J6.40, R32.1, U7.7, WP1.2
WP2: J10.40, R48.1, U11.7, WP2.2
WP3: J14.40, R64.1, U15.7, WP3.2
WP4: J18.40, R80.1, U19.7, WP4.2
WP5: J22.40, R96.1, U23.7, WP5.2

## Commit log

2021-08-17 Initial Commit (post-prototype, pre-finalized-for-REDs)
    [SparkFun_GNSS_NEO-M9N.GBL, SparkFun_GNSS_NEO-M9N.GBO, SparkFun_GNSS_NEO-M9N.GBP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]
2021-09-01 Correctly routes I2C to EEPROM chip
    [SparkFun_GNSS_NEO-M9N.brd, SparkFun_GNSS_NEO-M9N.sch]
2021-09-01 Moves to 0603 components where they can be, updates measures
    * Moves around vias for symmetrical appeal (though I burned out and so it's not)
    * Adds silk
    [SparkFun_GNSS_NEO-M9N.brd, SparkFun_GNSS_NEO-M9N.sch]
2021-09-08 Routes new switching ICs
    [SparkFun_GNSS_NEO-M9N.brd, SparkFun_GNSS_NEO-M9N.sch]
2021-09-08 Fixes various traces
    [SparkFun_GNSS_NEO-M9N.brd]
2021-09-09 Moves silk around, seeds new vias around the PCB
    [SparkFun_GNSS_NEO-M9N.brd, SparkFun_GNSS_NEO-M9N.sch]
2021-09-09 Adds more text to clarify selection jumper, fixes some clearance issues and wire stubs
    [SparkFun_GNSS_NEO-M9N.brd, SparkFun_GNSS_NEO-M9N.sch]
2021-09-09 Adds some vias, moves some silk
    [SparkFun_GNSS_NEO-M9N.brd, SparkFun_GNSS_NEO-M9N.sch]
2021-09-10 Adds labels to bus selection jumper
    [SparkFun_GNSS_NEO-M9N.brd]
2021-09-14 Cams new design, moves old gerbers to their own folders
    [SparkFun_GNSS_NEO-M9N.GBL, SparkFun_GNSS_NEO-M9N.GBO, SparkFun_GNSS_NEO-M9N.GBP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]
2021-09-24 Adds WP pin to schematic
    [SparkFun_GNSS_NEO-M9N.brd, SparkFun_GNSS_NEO-M9N.sch]
2021-09-24 Loosely adds placement of WP circuit to PCB
    [SparkFun_GNSS_NEO-M9N.brd, SparkFun_GNSS_NEO-M9N.sch]
2021-10-22 Adds WP pullup resistor and jumper to allow user control over the pin
    * Routes WP net to card's edge
    * Adds silk to WP jumper
    * Adjusts a few traces
    * Rolls version to v11
    [SparkFun_GNSS_NEO-M9N.brd, SparkFun_GNSS_NEO-M9N.sch]
2021-10-27 Add 0.1uF bypass cap to EEPROM VCC, moves two PTH header east to accommodate new cap
    * Adds "GNSS" silk
    * Flips silk on bottom so that all silk has uniform direction
    [SparkFun_GNSS_NEO-M9N.brd, SparkFun_GNSS_NEO-M9N.sch]
2021-11-03 Updates Function Board symbol
    [SparkFun_GNSS_NEO-M9N.brd, SparkFun_GNSS_NEO-M9N.sch]
2021-12-07 Switches SMA connector to PTH connector
    [SparkFun_GNSS_NEO-M9N.brd, SparkFun_GNSS_NEO-M9N.sch]
2021-12-07 Adds PTH SMA Connector to design
    [SparkFun_GNSS_NEO-M9N.brd, SparkFun_GNSS_NEO-M9N.sch]
2022-01-05 Adds a via, moves "L1" text
    [SparkFun_GNSS_NEO-M9N.brd, SparkFun_GNSS_NEO-M9N.sch]
2022-01-06 Adds PTH selection silk to bottom
    * Chnages MISO/MOSI net label -> PICO/POCI
    * Adds text explanation to safeboot pth selection
    * Moves some nets around for better ground pour
    * Adds a few vias
    * Adds measures to LEDs
    [SparkFun_GNSS_NEO-M9N.brd, SparkFun_GNSS_NEO-M9N.sch]
2022-01-07 Removes old gerbers
    [SparkFun_GNSS_NEO-M9N.GBL, SparkFun_GNSS_NEO-M9N.GBO, SparkFun_GNSS_NEO-M9N.GBP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]
2022-01-07 Added production files
    [SparkFun_GNSS_NEO-M9N-Panel.GBL, SparkFun_GNSS_NEO-M9N-Panel.GBO, SparkFun_GNSS_NEO-M9N-Panel.GBP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]
2022-03-30 Replaces SMA connector with u.FL
    [SparkFun_GNSS_NEO-M9N.brd, SparkFun_GNSS_NEO-M9N.sch]
2022-04-01 Replaces old ML414H reflowable with new MS421R
    [SparkFun_GNSS_NEO-M9N.brd, SparkFun_GNSS_NEO-M9N.sch]
2022-04-04 Rotates board for paneling and corrected PCB edge
    [SparkFun_GNSS_NEO-M9N.brd]
2022-04-04 Updated production files to v12
    [SparkFun_GNSS_NEO-M9N-Panel.brd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]
2022-04-04 Uses the updated function board outline
    [SparkFun_GNSS_NEO-M9N.brd, SparkFun_GNSS_NEO-M9N.sch]
2022-04-05 Corner dimension fix
    [SparkFun_GNSS_NEO-M9N.brd]
2022-04-05 Revised panel
    [SparkFun_GNSS_NEO-M9N-Panel.GBL, SparkFun_GNSS_NEO-M9N-Panel.GBO, SparkFun_GNSS_NEO-M9N-Panel.GBS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]
2022-04-05 Moves production out to main directory
    * Appends version number to zipped production files
    [SparkFun_GNSS_NEO-M9N-Panel.GBL, SparkFun_GNSS_NEO-M9N-Panel.GBO, SparkFun_GNSS_NEO-M9N-Panel.GBP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]
2022-04-07 Corrects typo on "u-blox" in schematic
    [SparkFun_GNSS_NEO-M9N.sch]

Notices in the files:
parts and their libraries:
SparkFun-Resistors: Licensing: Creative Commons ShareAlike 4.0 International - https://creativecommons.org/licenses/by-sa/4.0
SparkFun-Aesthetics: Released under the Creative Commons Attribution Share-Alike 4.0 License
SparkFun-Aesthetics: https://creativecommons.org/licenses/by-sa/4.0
